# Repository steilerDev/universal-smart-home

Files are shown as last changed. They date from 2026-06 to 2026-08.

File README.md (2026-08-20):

# universal-smart-home

ESPHome firmware for the house: ~25 room sensor units plus a handful of special-purpose
nodes. Every device is an [Olimex ESP32-POE2](https://www.olimex.com/Products/IoT/ESP32/ESP32-POE2/open-source-hardware)
on PoE Ethernet — no WiFi, no cloud dependency. All devices integrate with Home
Assistant via the native ESPHome API. This repo is the single source of truth for
every device configuration.

---

## Hardware — Room Sensor

> [Schematic](https://app.cirkitdesigner.com/project/281a6c22-06b7-4593-8d16-d8be4f0f2b7c)

| Component | Part |
|---|---|
| MCU | [Olimex ESP32-POE2](https://www.olimex.com/Products/IoT/ESP32/ESP32-POE2/open-source-hardware) (ESP32-WROVER-E, PoE Ethernet) |
| Climate | [ENS160](https://esphome.io/components/sensor/ens160/) + [AHT21](https://esphome.io/components/sensor/aht10/) — eCO2, TVOC, AQI, temp, humidity |
| Illuminance | [BH1750](https://esphome.io/components/sensor/bh1750/) |
| Presence | [DFRobot C4002](https://www.dfrobot.com/product-3081.html) mmWave radar (custom component) |
| Dimmer | [KRIDA I2C AC dimmer](https://www.tindie.com/products/bugrovs2012/i2c-mosfet-trailing-edge-ac-dimmer-light) trailing-edge MOSFET (custom component) |
| GPIO Expander | [PCF8574](https://esphome.io/components/pcf8574/) — 2 buttons, 2 power circuits, 2 roller blinds |
| Status LED | WS2811/WS2812 via [esp32_rmt_led_strip](https://esphome.io/components/light/esp32_rmt_led_strip/) |
| Audio | [ES8311](https://esphome.io/components/audio_dac/es8311/) + NS4150B (notifications / TTS) |
| Power | [PZEM-004T](https://esphome.io/components/sensor/pzemac/) AC energy monitor |

PCB design files live in `hardware/pcb/`, the enclosure in `hardware/case/room-sensor/`.

---

## Hardware — Utility Sensor

The basement metering node. Same Olimex board, **no custom PCB** — the field wiring
lands on screw terminals — but it does have its own case (`hardware/case/utility-sensor/`).

| Component | Part |
|---|---|
| MCU | Olimex ESP32-POE2, running the `esp-idf` framework (8 × PCNT pulse counters) |
| Water flow | 8 × YF-B series hall-effect meters, one per supply line |
| Well level | QDY30A submersible level transmitter (Modbus RTU over RS485) |
| Grid power | Eastron SDM three-phase meter (Modbus RTU) — wired for, **not yet populated** |

Schematic (WIP): https://app.cirkitdesigner.com/project/46fdfdfb-f6f8-4aec-ac91-cfc2bc7dc07d

### Metered lines

| Line | GPIO | Line | GPIO |
|---|---|---|---|
| EG Kalt | GPIO04 | EG Warm | GPIO36 |
| OG Kalt | GPIO33 | OG Warm | GPIO13 |
| EG Heizung | GPIO15 | OG Heizung | GPIO02 |
| Anbau Heizung | GPIO14 | Brunnen | GPIO05 |

### Calibration

Both are build-time values in `devices/utility-sensor.yaml` — change and re-flash.

- **Water meters** — `flow_pulses_per_liter` per line. Meter datasheets quote
  `F = K * Q` (F in Hz, Q in L/min), so pulses/L is `K * 60`; the YF-B's K = 6.6 gives
  396. Each line carries its own value, so lines with a different meter model just get
  a different number.

  After changing a line's calibration, **re-flash and then press its
  `Water Volume Reset - <line>` button in HA**. The running total is stored in flash
  keyed by entity, so it survives the OTA and would otherwise keep the volume that
  was accumulated with the old pulses/L.
- **Well level** — the probe measures the water column above *itself*. The published
  value is the column above the **pump intake**:
  `raw + (well_pump_depth_cm - well_sensor_depth_cm)`. The offset is +100 cm in this
  install (probe at 15 m, intake at 16 m); it would be negative if the probe hung
  below the intake. Negative readings mean the water is below the intake and are not
  clamped away.

  ⚠️ Because the probe sits **above** the intake it cannot see a surface below itself,
  so the last 100 cm above the intake all read 100 cm — a floor, not a level. The
  `Well Probe Uncovered` binary sensor (`device_class: problem`) is ON exactly then, so
  automations can treat that reading as "≤100 cm, unknown" rather than trusting it.
  Hanging the probe below the intake would remove the blind spot.

### Home Assistant water dashboard

The `Water Volume - <line>` sensors carry `device_class: water` +
`state_class: total_increasing`, which is what HA's water dashboard filters on. A unit
of `L` alone is not enough — the entity simply never appears in the picker without
both of those.

---

## Repository Layout

```
devices/          — One YAML per physical device (substitutions + package includes)
packages/
  base/           — Board, Ethernet, OTA, HA API (room-sensor / utility-sensor variants)
  sensors/        — climate, illuminance, motion, power-pzem004t, water-flow,
                    well-level, energy-sdm
  actuators/      — status-led, dimmer, audio
  io/             — gpio-extender (PCF8574 — buttons, power circuits, blinds)
  displays/       — trmnl (e-ink dashboard)
components/       — Local custom ESPHome components (dfrobot_c4002, krida_dimmer, trmnl)
hardware/
  pcb/            — KiCad projects, symbol/footprint libs, LCSC BOM
  case/           — Fusion 360 enclosures, one directory per device
deploy/           — Device Builder deployment notes
scripts/          — validate-all, builder-deploy, deploy, new-device, check-device
sounds/           — WAV assets for the audio package
secrets.template.yaml
```

---

## Deployed Devices

| Device | IP | Packages |
|---|----|---|
| `room-sensor-poe2` (prototype) | 10.10.14.20 | base, power, climate, motion, status\_led |
| `eink-dashboard` | 10.10.14.25 | base, trmnl |
| `utility-sensor` | 10.10.14.10 | base, well\_level, 8 × water\_flow |

---

## Quick Start

Firmware is compiled and OTA-flashed by the self-hosted **ESPHome Device Builder**,
not by compiling locally — see [`deploy/README.md`](deploy/README.md).

```bash
cp secrets.template.yaml secrets.yaml  # fill in OTA password + HA encryption key

esphome config devices/<name>.yaml     # 1. validate (cheap, no compile)
./scripts/builder-deploy.py <name>     # 2. compile + OTA on the builder
./scripts/check-device.py <name>       # 3. post-deploy health check
```

Add a new device:

```bash
./scripts/new-device.sh <room-name>
```

Local compilation (`pip3 install esphome --break-system-packages`, then
`esphome run devices/<name>.yaml`) still works as a fallback; see `CLAUDE.md` for the
PlatformIO workarounds it needs.

---

## Packages

Each device YAML picks only the packages it needs. Every device requires exactly one
`base` package; the rest are optional.

| Package | Provides |
|---|---|
| `base/room-sensor` | Board (arduino), Ethernet PoE, OTA, HA API, I2C bus |
| `base/utility-sensor` | Board (esp-idf), Ethernet PoE, OTA, HA API — no I2C |
| `sensors/climate` | [ENS160](https://esphome.io/components/sensor/ens160/) + [AHT20](https://esphome.io/components/sensor/aht10/) — air quality, temp, humidity |
| `sensors/illuminance` | [BH1750](https://esphome.io/components/sensor/bh1750/) light level |
| `sensors/motion` | [DFRobot C4002](https://www.dfrobot.com/product-3081.html) presence + target tracking |
| `sensors/power-pzem004t` | [PZEM-004T](https://esphome.io/components/sensor/pzemac/) AC voltage/current/power/energy |
| `sensors/water-flow` | Pulse water meter for one supply line — include once per line with `vars` |
| `sensors/well-level` | QDY30A submersible level transmitter over Modbus |
| `sensors/energy-sdm` | Eastron SDM three-phase grid meter over Modbus |
| `actuators/dimmer` | [KRIDA I2C AC dimmer](https://www.tindie.com/products/bugrovs2012/i2c-mosfet-trailing-edge-ac-dimmer-light) (light entity) |
| `actuators/status-led` | WS2811/WS2812 status LED via [esp32_rmt_led_strip](https://esphome.io/components/light/esp32_rmt_led_strip/) |
| `actuators/audio` | [ES8311](https://esphome.io/components/audio_dac/es8311/) I2S media player |
| `io/gpio-extender` | [PCF8574](https://esphome.io/components/pcf8574/) — buttons, switches, blind covers |
| `displays/trmnl` | TRMNL BYOS e-ink dashboard client (custom component) |

`sensors/water-flow` is the one package meant to be included several times per device.
Use the mapping form of `!include` to pass it per-instance variables:

```yaml
packages:
  flow_eg_kalt: !include
    file: ../packages/sensors/water-flow.yaml
    vars:
      flow_key: eg_kalt
      flow_name: "EG Kalt"
      flow_pin: "GPIO04"
      flow_pulses_per_liter: "396"
```

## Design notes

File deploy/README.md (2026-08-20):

# Deploying firmware via the ESPHome Device Builder

Firmware is compiled and OTA-flashed by the self-hosted **ESPHome Device Builder**
container, not by compiling in the agent's environment.

```
host checkout ──bind-mount──► esphome (builder)   (runs the builder on devices/)
              └─bind-mount──► coder / agent      (edits devices/*.yaml)
                                 │  same files — edits are visible instantly ↑
  agent ── ws://esphome:6052/ws (no auth) ──────┘  compile + OTA
  browsers ── https://esphome.<domain> ── Authentik SSO ──► esphome (builder)
```

- **Shared mount, no git-sync** — the agent and the builder see the *same* files on
  disk, so a YAML edit is visible to the builder immediately. No commit or push is
  required to flash.
- **Git stays the source of truth** — `commit + push` is a durability step *after* a
  successful deploy, not part of the deploy path.
- **No auth for the agent** — it reaches the builder directly on the internal Docker
  network. The builder's native auth is unset (`requires_auth: false`); Authentik only
  gates the browser UI.

## Builder endpoint

| | |
|---|---|
| WebSocket API (agent) | `ws://esphome:6052/ws` |
| Browser UI | `https://esphome.<domain>` (Authentik SSO) |

Set `ESPHOME_BUILDER_URL=ws://esphome:6052/ws` in the agent's environment, or pass
`--server` to `scripts/builder-deploy.py`.

## Deploy loop

```bash
esphome config devices/room-sensor-poe2.yaml   # 1. validate locally (cheap, no compile)
./scripts/builder-deploy.py room-sensor-poe2   # 2. compile + OTA on the builder, streamed
./scripts/check-device.py room-sensor-poe2     # 3. health check
git add -A && git commit -m "…" && git push origin main   # 4. persist (durability)
```

The `deploy-device` skill codifies this loop.

`scripts/builder-deploy.py` speaks the builder's single `/ws` endpoint, streams job
output, and exits non-zero if any job fails. `--all` deploys every device;
`--compile-only` skips the OTA upload.

**A deploy is two jobs, not one.** On this builder (1.0.12 / ESPHome 2026.6.2)
`firmware/install` only *compiles* — its job ends at "Successfully compiled program"
and never contacts the device. The OTA is a separate `firmware/upload` job
(`job_type: upload`). The script runs `firmware/install` → `firmware/upload`, each
followed via `firmware/follow_job`. Calling install alone reports a green deploy
while the device keeps running its old firmware.

## Troubleshooting

| Symptom | Cause |
|---|---|
| `firmware/upload`: `Connecting to <ip> port 3232 failed: [Errno 113] No route to host` | **Nothing answers at that IP.** Port 3232 is the ESPHome OTA port; ARP finding no host produces this error, which reads like a routing fault but usually means `device_ip` is wrong (or the device is powered down). Verify the address before touching any network config. |
| `firmware/install` says SUCCESS but the device behaves as before | Expected — install only compiles. The OTA is the separate `firmware/upload` job; see above. |

## Why the builder's config dir points at `devices/`

The builder's config scanner (`list_yaml_files`) is **top-level only** and skips
`secrets.yaml` and dotfiles. Our device YAMLs live in `devices/` and
`!include ../packages/...`, so the container mounts the **whole repo** but runs the
dashboard against the `devices/` subdirectory. Includes,
`external_components: ../components`, and the `devices/secrets.yaml → ../secrets.yaml`
symlink all resolve because the parent tree is present on disk.

`secrets.yaml` is gitignored and lives at the checkout **root**; the committed
`devices/secrets.yaml` symlink points at it, so the builder finds secrets when
compiling `devices/*.yaml`.

## Notes

- **Source of truth is the YAML in git.** Treat the builder UI as deploy/observe only;
  set friendly names via device-YAML `substitutions`, so the gitignored builder state
  (`.device-builder*.json`) stays disposable.
- The builder image's default `CMD` is `dashboard /config`; its entrypoint rewrites the
  `dashboard` subcommand to the Device Builder backend (`esphome-device-builder`). Any
  other first arg is passed to the plain `esphome` CLI, so the builder `command` **must**
  begin with `dashboard`. Verified on 2026.6.2 and 2026.6.5. Pin a tag instead of
  `:latest` for reproducibility.

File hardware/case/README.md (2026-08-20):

# Cases

One directory per enclosure. Each holds the Fusion 360 source plus its exports.

| Case | For | Custom PCB? |
|---|-----|---|
| [`room-sensor/`](room-sensor/) | Room sensor units (~25×) | Yes — `hardware/pcb/RoomSensor-{Main,Back}Plate` |
| [`utility-sensor/`](utility-sensor/) | Utility sensor (basement metering) | No — Olimex board + screw terminals only |

## File conventions

- `*.f3d` — Fusion 360 native source (the editable master)
- `*.step` — STEP export, opens without Fusion 360
- `*.stl` — print-ready mesh
- `renders/` — PNG renders exported from Fusion 360

CAD files are marked `binary` in `.gitattributes` so git never tries to diff or
merge them. That also means **they do not merge** — coordinate before editing one.

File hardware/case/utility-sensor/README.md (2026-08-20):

# Utility Sensor Case

Custom enclosure for the basement metering unit, designed in Fusion 360.

Unlike the room sensors this device has **no custom PCB** — it is a stock
[Olimex ESP32-POE2](https://www.olimex.com/Products/IoT/ESP32/ESP32-POE2/open-source-hardware)
with the water-meter and RS485 wiring landed straight on screw terminals. The
case is therefore the only custom-fabricated part, which is why it is tracked
here on its own.

## What it has to hold

| Item | Notes |
|---|---|
| Olimex ESP32-POE2 | Standoffs; RJ45 must reach the wall |
| 8 × water meter leads | Pulse + 3.3V + GND per line — see `devices/utility-sensor.yaml` for the GPIO map |
| RS485 leg → well probe | QDY30A submersible level transmitter |
| RS485 leg → grid meter | Eastron SDM — wired for, not yet populated |

## Design Files

- `*.f3d` — Fusion 360 native source (stored as binary in git)
- `*.step` — STEP export (open without Fusion 360)
- `*.stl` — print-ready STL export
- `renders/` — PNG renders exported from Fusion 360

> ⚠️ **The CAD files are not in the repo yet.** The device was built before this
> repo existed. Export the current Fusion 360 design into this directory
> (`.f3d` + `.step` + `.stl`) so the case stops living only in someone's Fusion
> cloud project.

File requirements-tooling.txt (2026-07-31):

# Tooling deps for the scripts/ helpers (not firmware deps).
#   pip3 install -r requirements-tooling.txt
websockets>=13        # scripts/builder-deploy.py  (Device Builder /ws client)
aioesphomeapi         # scripts/check-device.py    (native-API health check)
PyYAML                # device/secret YAML parsing in scripts/

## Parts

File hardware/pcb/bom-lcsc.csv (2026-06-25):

MPN | LCSC# | Qty (1 board set) | Description | Refs
C50950 | C50950 | 2 | 1x5 female socket 8.5mm | MainPlate S1, S2
C27438 | C27438 | 1 | 1x8 female socket 8.5mm | MainPlate S3
PM254-1-10-Z-8.5 | C2897373 | 1 | 1x10 female socket 8.5mm | MainPlate A1
C64320 | C64320 | 1 | 2x13 dual female socket 8.5mm | MainPlate E1
KF128-2.54-4P | C474922 | 5 | 4-pin screw terminal 2.54mm | MainPlate C1, C2 + BackPlate EX1, EX2, EX3
KF128-2.54-7P | C474925 | 1 | 7-pin screw terminal 2.54mm | MainPlate C3
MTB10-10S | C358743 | 2 | IDC 2x5 box header 2.54mm PCB side | MainPlate J1, BackPlate C1
HX PM2.54-1x4P ZC H11 | C41427519 | 5 | 4-pin tall female socket 11mm | BackPlate R1, R2, R3, L1, E1
PCF8574P | C398073 | 1 | DIP-16 I2C GPIO expander | BackPlate U1

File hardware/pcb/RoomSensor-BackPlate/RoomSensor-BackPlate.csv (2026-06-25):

Qty | MPN
1 | 2.54-2*5P
5 | HX PM2.54-1x4P ZC H11
3 | KF128-2.54-4P
1 | PCF8574P
1 | PM254-1-10-Z-8.5
2 | KF128-2.54-4P
1 | KF128-2.54-7P
1 | 2.54-2*13PFemale
1 | 2.54-2*5P
2 | 2.54-1*5PFemale
1 | 2.54-1*8P

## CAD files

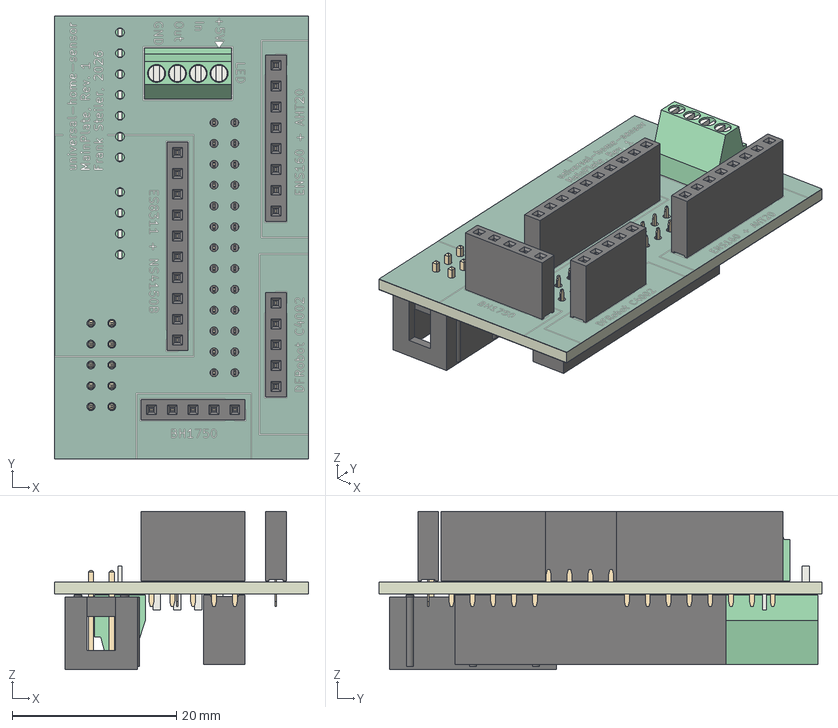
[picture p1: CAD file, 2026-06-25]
hardware/pcb/RoomSensor-MainPlate/MainPlate.step
31.0 x 54.0 x 19.3 mm
PinSocket_1x08_P2.54mm_Vertical
PinSocket_1x05_P2.54mm_Vertical x 2
PinSocket_1x10_P2.54mm_Vertical
TerminalBlock_Phoenix_MPT-0,5-4-2.54_1x04_P2.54mm_Horizontal x 2
TerminalBlock_Phoenix_MPT-0,5-7-2.54_1x07_P2.54mm_Horizontal
PinSocket_2x13_P2.54mm_Vertical
IDC_Header_2x05_P254mm_Vertical
RoomSensor-MainPlate_silkscreen x 2
RoomSensor-MainPlate_soldermask x 2
RoomSensor-MainPlate_PCB

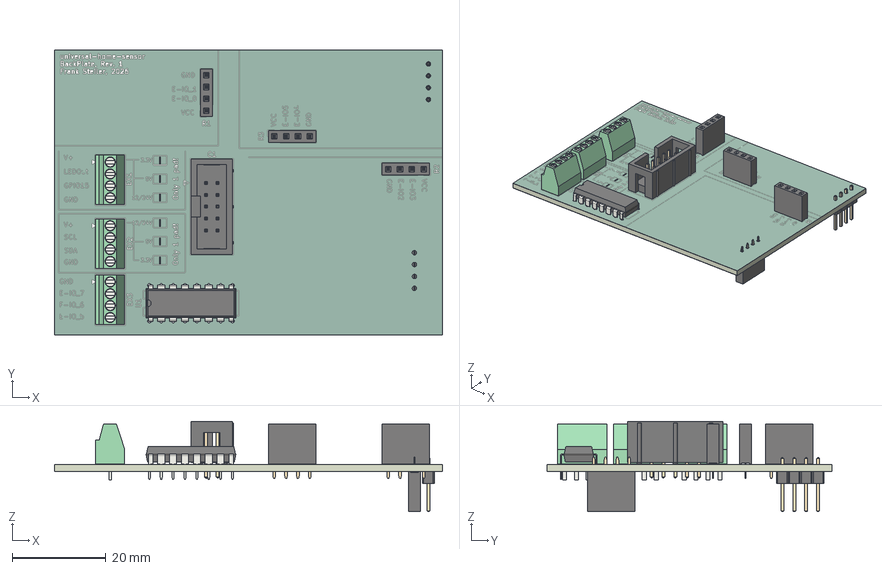
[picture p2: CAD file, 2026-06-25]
hardware/pcb/RoomSensor-BackPlate/BackPlate.step
83.0 x 61.0 x 19.3 mm
PinSocket_1x04_P2.54mm_Vertical x 4
DIP-16_W7.62mm
TerminalBlock_Phoenix_MPT-0,5-4-2.54_1x04_P2.54mm_Horizontal x 3
IDC_Header_2x05_P254mm_Vertical
PinHeader_1x04_P254mm_Vertical
RoomSensor-BackPlate-unsaved-export-98Ihw8_silkscreen x 2
RoomSensor-BackPlate-unsaved-export-98Ihw8_soldermask x 2
RoomSensor-BackPlate-unsaved-export-98Ihw8_PCB

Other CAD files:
hardware/pcb/RoomSensor-BackPlate/BackPlate.stl

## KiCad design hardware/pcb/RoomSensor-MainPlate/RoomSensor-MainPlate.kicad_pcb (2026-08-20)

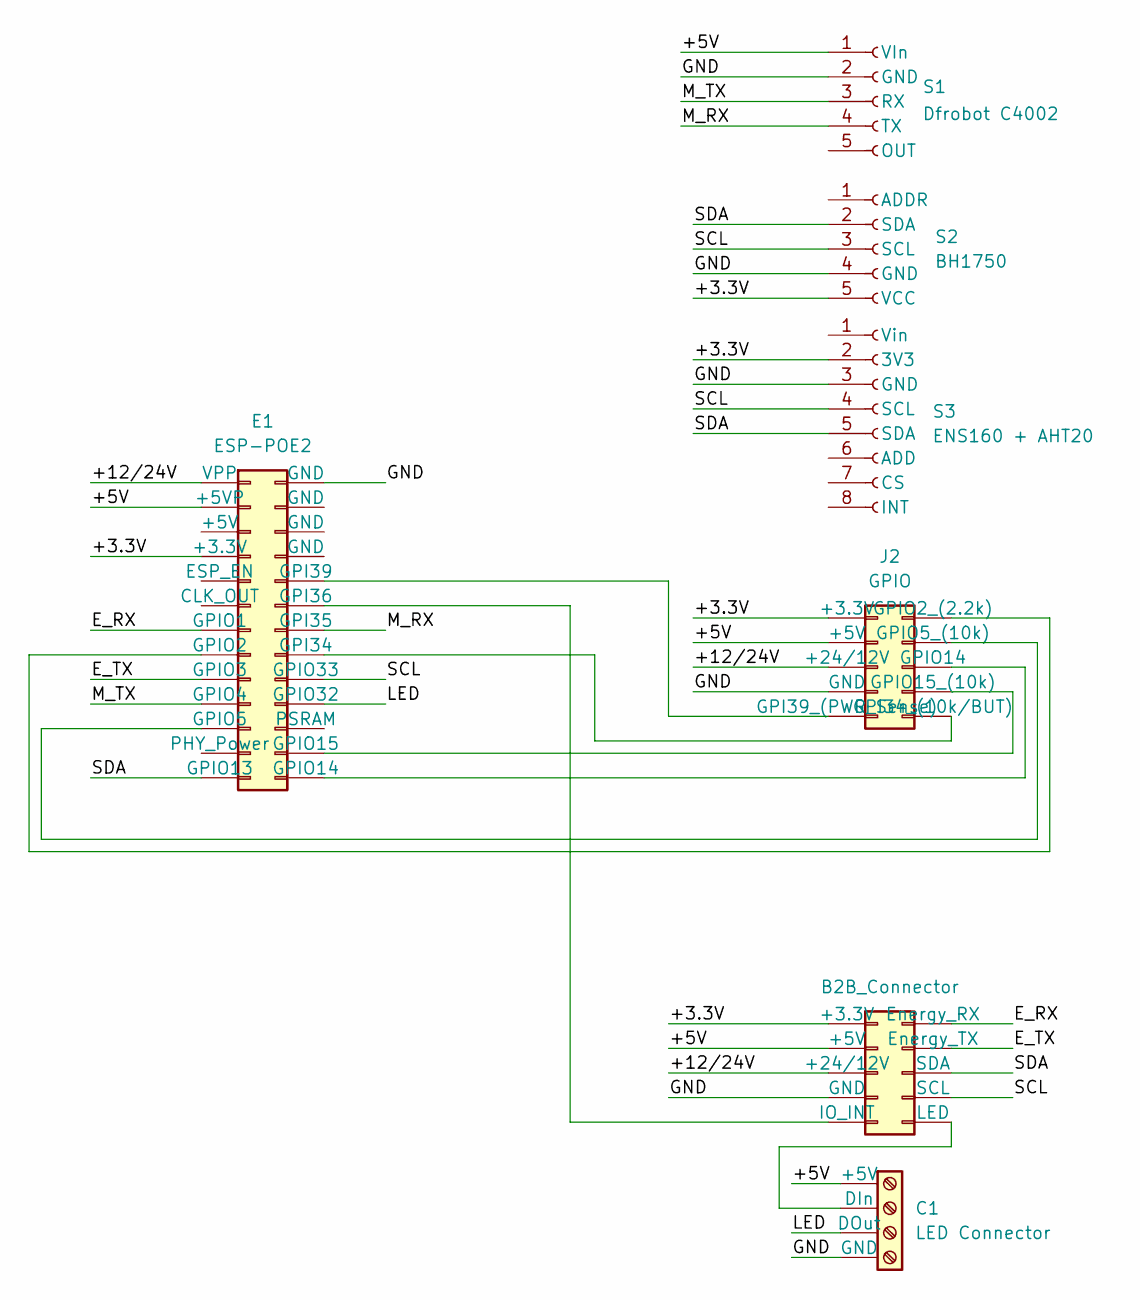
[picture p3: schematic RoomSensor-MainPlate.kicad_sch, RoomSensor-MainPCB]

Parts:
C1: LED Connector; TerminalBlock_Phoenix_MPT-0,5-4-2.54_1x04_P2.54mm_Horizontal; MPN KF128-2.54-4P
E1: ESP-POE2; PinSocket_2x13_P2.54mm_Vertical; MPN C64320
J1: B2B_Connector; B2B Connector; MPN MTB10-10S
J2: GPIO; IDC-Header_2x05_P2.54mm_Vertical; MPN MTB10-10S
S1: Dfrobot C4002; DFRobot C4002 Connector; MPN C50950
S2: BH1750; MPN C50950
S3: ENS160 + AHT20; ENS160 + AHT20 Connector; MPN C27438

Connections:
/+3.3V: E1.7 (+3.3V), J1.1 (+3.3V), J2.1 (+3.3V), S2.5 (VCC), S3.2 (3V3)
/+5V: C1.1 (+5V), E1.3 (+5VP), J1.3 (+5V), J2.3 (+5V), S1.1 (VIn)
/+12/24V: E1.1 (VPP), J1.5 (+24/12V), J2.5 (+24/12V)
/E_RX: E1.13 (GPIO1), J1.2 (Energy_RX)
/E_TX: E1.17 (GPIO3), J1.4 (Energy_TX)
/GND: C1.4 (GND), E1.2 (GND), J1.7 (GND), J2.7 (GND), S1.2 (GND), S2.4 (GND), S3.3 (GND)
/LED: C1.3 (DOut), E1.20 (GPIO32)
/M_RX: E1.14 (GPI35), S1.4 (TX)
/M_TX: E1.19 (GPIO4), S1.3 (RX)
/SCL: E1.18 (GPIO33), J1.8 (SCL), S2.3 (SCL), S3.4 (SCL)
/SDA: E1.25 (GPIO13), J1.6 (SDA), S2.2 (SDA), S3.5 (SDA)
unnamed: C1.2 (DIn), J1.10 (LED)
unnamed: E1.16 (GPI34), J2.10 (GPI34_(10k/BUT))
unnamed: E1.12 (GPI36), J1.9 (IO_INT)
unnamed: E1.10 (GPI39), J2.9 (GPI39_(PWR_Sense))
unnamed: E1.15 (GPIO2), J2.2 (GPIO2_(2.2k))
unnamed: E1.21 (GPIO5), J2.4 (GPIO5_(10k))
unnamed: E1.26 (GPIO14), J2.6 (GPIO14)
unnamed: E1.24 (GPIO15), J2.8 (GPIO15_(10k))

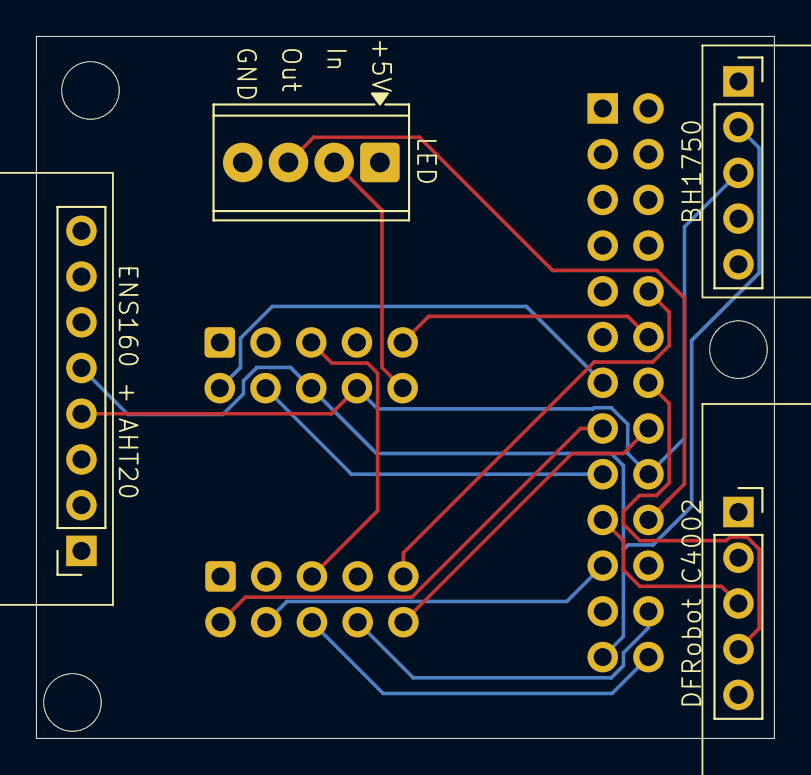
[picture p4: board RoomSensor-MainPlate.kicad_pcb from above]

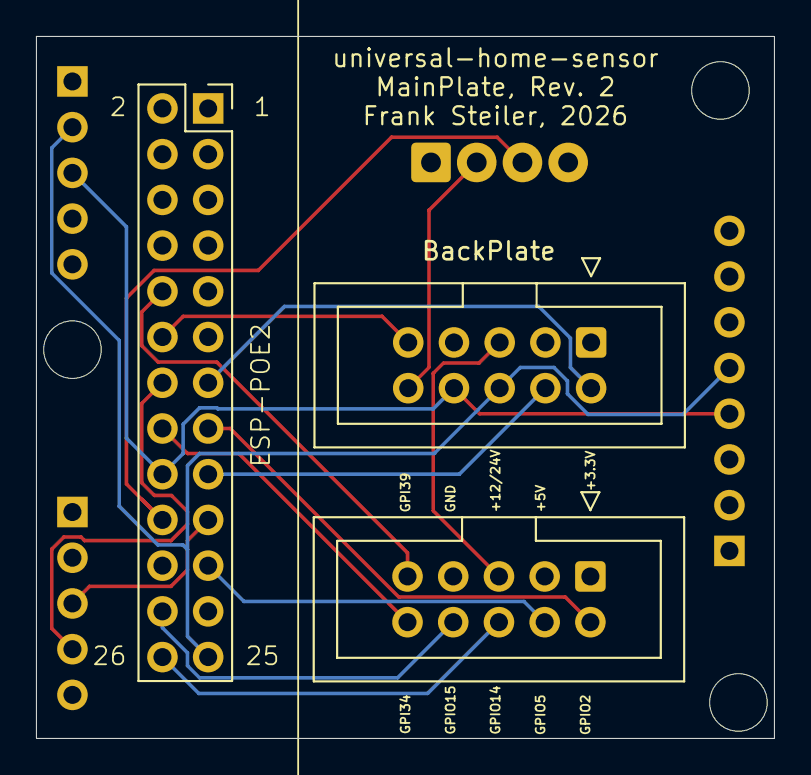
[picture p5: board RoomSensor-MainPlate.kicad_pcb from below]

Board: 4 copper layers, 41.0 x 39.0 mm, 7 parts (3 on the bottom side), 19 nets.

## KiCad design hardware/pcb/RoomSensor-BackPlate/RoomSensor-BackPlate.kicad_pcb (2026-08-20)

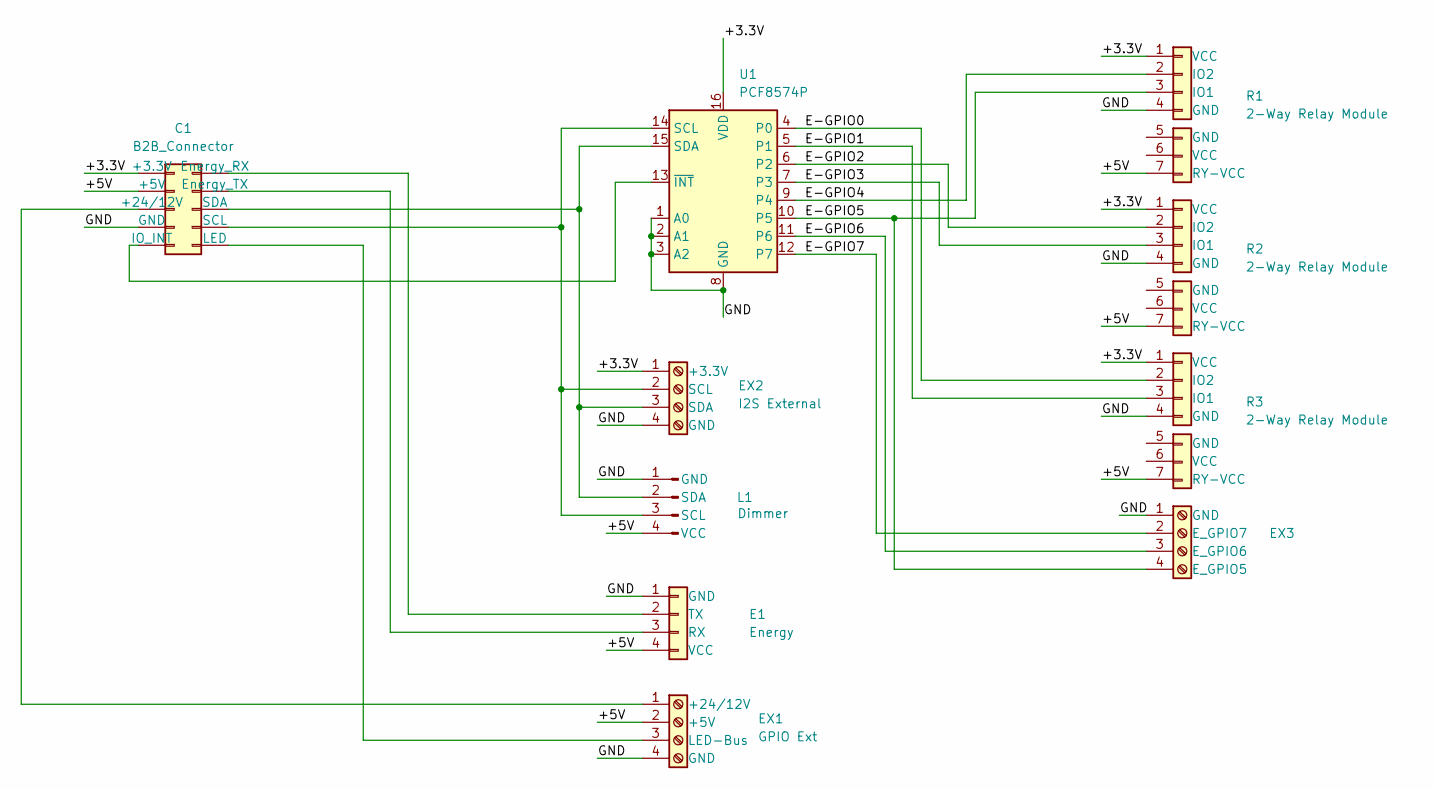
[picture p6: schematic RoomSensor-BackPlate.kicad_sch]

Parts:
C1: B2B_Connector; IDC-Header_2x05_P2.54mm_Vertical; MPN MTB10-10S
E1: Energy; PZEM-004T Connector; MPN HX PM2.54-1x4P ZC H11
EX1: GPIO Ext; TerminalBlock_Phoenix_MPT-0,5-4-2.54_1x04_P2.54mm_Horizontal; MPN KF128-2.54-4P
EX2: I2S External; TerminalBlock_Phoenix_MPT-0,5-4-2.54_1x04_P2.54mm_Horizontal; MPN KF128-2.54-4P
EX3: Buttons; TerminalBlock_Phoenix_MPT-0,5-4-2.54_1x04_P2.54mm_Horizontal; MPN KF128-2.54-4P
L1: Dimmer; Krida Dimmer I2C Connector; MPN HX PM2.54-1x4P ZC H11
R1, R2, R3: 2-Way Relay Module; 2-way Relay Connector; MPN HX PM2.54-1x4P ZC H11
U1: PCF8574P; DIP-16_W7.62mm; MPN PCF8574P

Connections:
/+3.3V: C1.1 (+3.3V), EX2.1 (+3.3V), R1.1 (VCC), R2.1 (VCC), R3.1 (VCC), U1.16 (VDD)
/+5V: C1.3 (+5V), E1.4 (VCC), EX1.2 (+5V), L1.4 (VCC), R1.7 (RY-VCC), R2.7 (RY-VCC), R3.7 (RY-VCC)
/E-GPIO0: R3.2 (IO2), U1.4 (P0)
/E-GPIO1: R3.3 (IO1), U1.5 (P1)
/E-GPIO2: R2.2 (IO2), U1.6 (P2)
/E-GPIO3: R2.3 (IO1), U1.7 (P3)
/E-GPIO4: R1.2 (IO2), U1.9 (P4)
/E-GPIO5: EX3.4 (E_GPIO5), R1.3 (IO1), U1.10 (P5)
/E-GPIO6: EX3.3 (E_GPIO6), U1.11 (P6)
/E-GPIO7: EX3.2 (E_GPIO7), U1.12 (P7)
/GND: C1.7 (GND), E1.1 (GND), EX1.4 (GND), EX2.4 (GND), EX3.1 (GND), L1.1 (GND), R1.4 (GND), R2.4 (GND), R3.4 (GND), U1.1 (A0), U1.2 (A1), U1.3 (A2), U1.8 (GND)
unnamed: C1.5 (+24/12V), EX1.1 (+24/12V)
unnamed: C1.2 (Energy_RX), E1.2 (TX)
unnamed: C1.4 (Energy_TX), E1.3 (RX)
unnamed: C1.9 (IO_INT), U1.13 (~INT)
unnamed: C1.10 (LED), EX1.3 (LED-Bus)
unnamed: C1.8 (SCL), EX2.2 (SCL), L1.3 (SCL), U1.14 (SCL)
unnamed: C1.6 (SDA), EX2.3 (SDA), L1.2 (SDA), U1.15 (SDA)

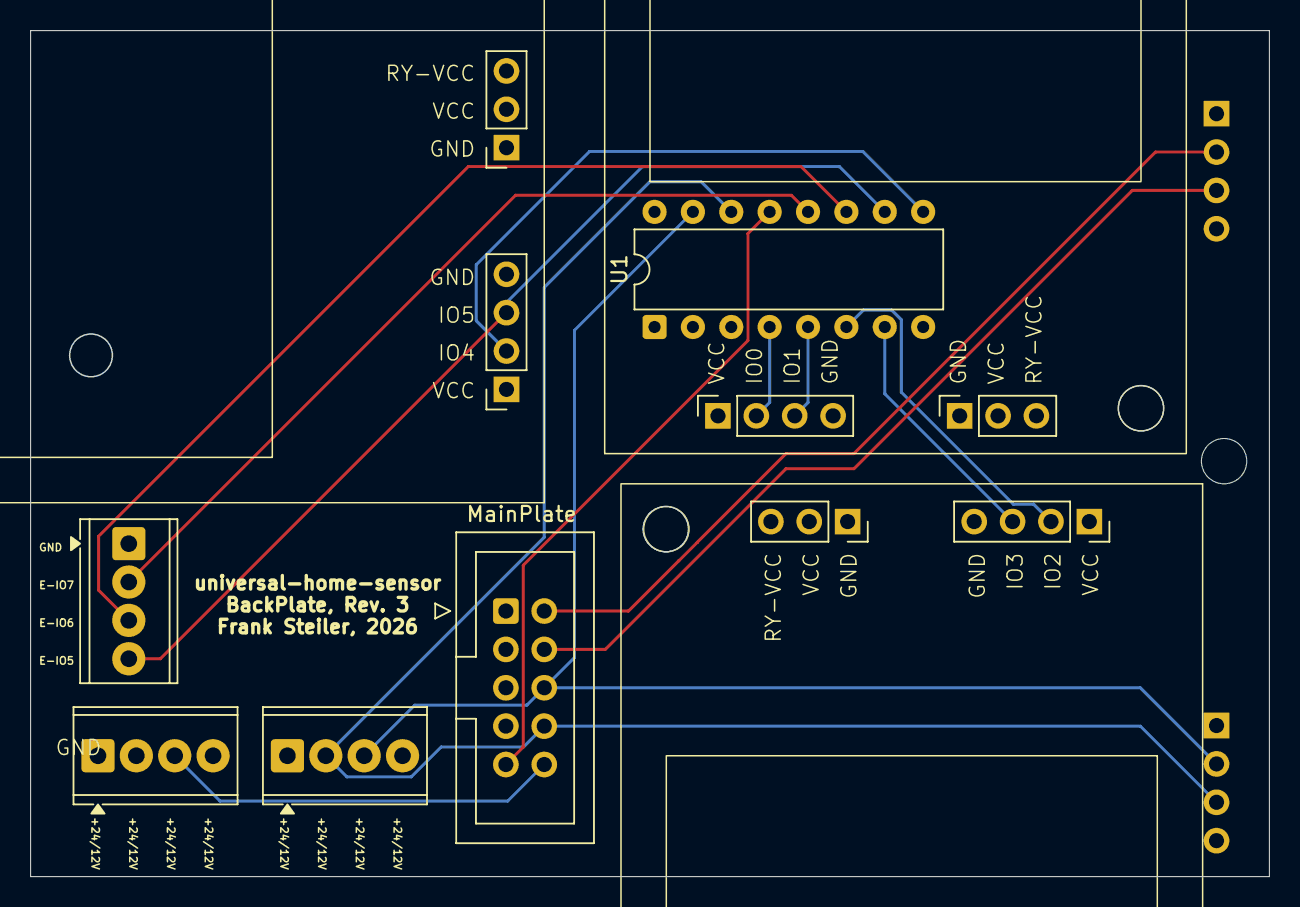
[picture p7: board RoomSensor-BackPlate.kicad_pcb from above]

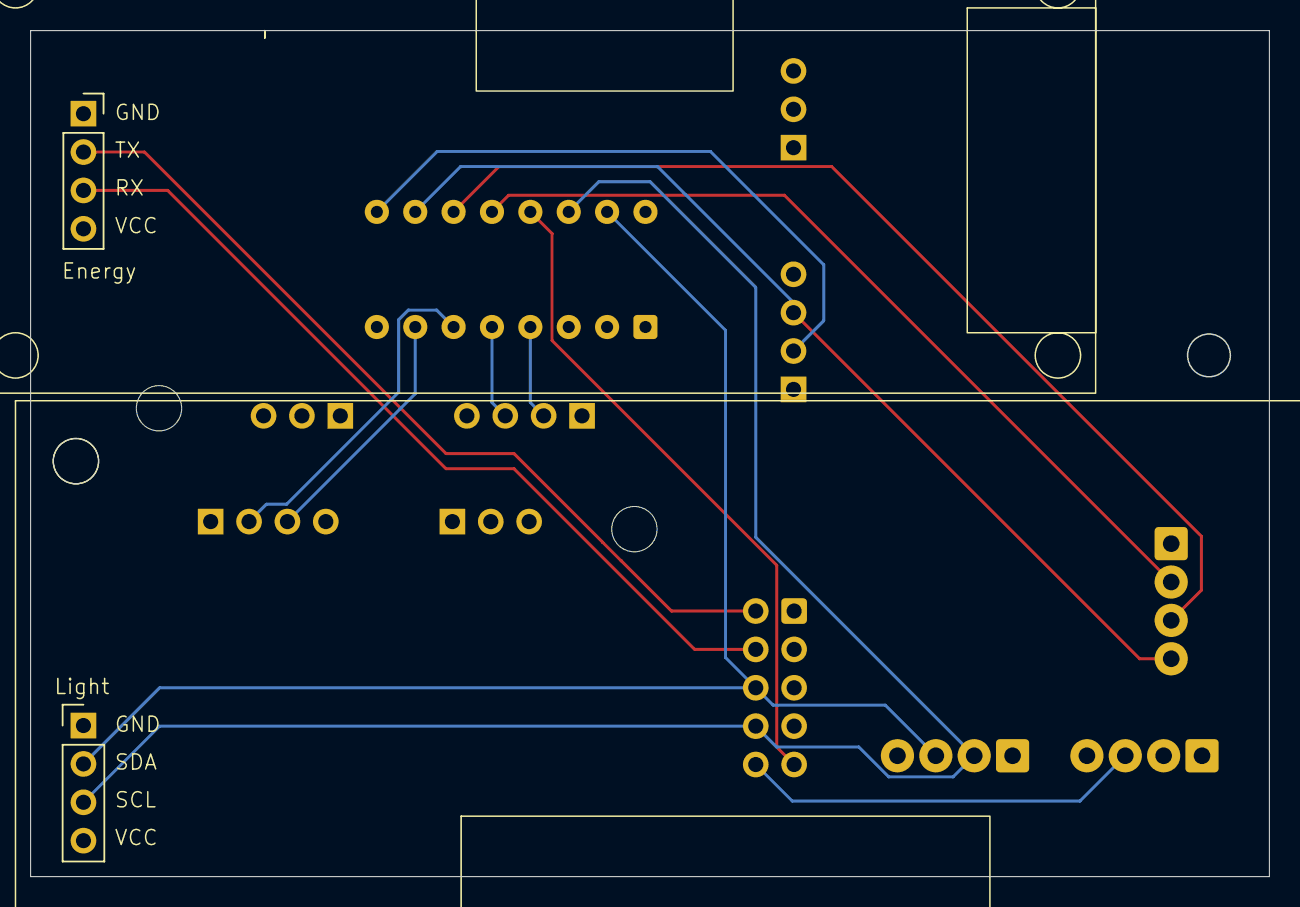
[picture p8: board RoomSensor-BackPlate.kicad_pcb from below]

Board: 4 copper layers, 82.0 x 56.0 mm, 10 parts (2 on the bottom side), 18 nets.

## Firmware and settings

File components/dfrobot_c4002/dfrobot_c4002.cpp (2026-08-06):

#include "dfrobot_c4002.h"
#include <string>
#include <cstdio>

namespace esphome {
namespace dfrobot_c4002 {

static const char *const TAG = "dfrobot_c4002: ";

void C4002Component::setup() {
  update_config_param();
  if (!this->is_failed()) {
    this->publish_text("C4002 initialized");
  }
}

void C4002Component::dump_config() {
  ESP_LOGCONFIG(TAG, "DFRobot C4002 mmWave Radar:");
  if (this->is_failed()) {
    if (this->last_uart_probe_bytes_ == 0) {
      ESP_LOGE(TAG, "  FAILED: no bytes received from sensor");
      ESP_LOGE(TAG, "  -> check power (VCC/GND) and that sensor TX -> ESP GPIO36");
    } else if (this->last_uart_probe_bytes_ > 0) {
      ESP_LOGE(TAG, "  FAILED: %d bytes received but frame invalid", this->last_uart_probe_bytes_);
      ESP_LOGE(TAG, "  -> possible baud rate mismatch or protocol error");
    } else {
      ESP_LOGE(TAG, "  FAILED: begin() not attempted (init error)");
    }
  } else {
    ESP_LOGCONFIG(TAG, "  Setup successful, detect range: %d cm", max_detect_range_cm_);
  }
}

void C4002Component::print_config() { ESP_LOGD(TAG, "run print config"); }

void C4002Component::loop() {
  static uint32_t last_time = 0;
  uint32_t now = millis();
  RetResult ret = {};

  ret = get_note_info_loop();
  if (ret.noteType == NOTE_INFO_RESULT) {
    ESP_LOGV(TAG, "NOTE_INFO_RESULT");
  } else if (ret.noteType == NOTE_INFO_CALIBRATION) {
    char msg[80];
    if (ret.calibCountdown > 0) {
      snprintf(msg, sizeof(msg), "Calibrating: %d s remaining...", ret.calibCountdown);
      this->publish_text(msg);
      ESP_LOGD(TAG, "Calibration countdown: %2d s", ret.calibCountdown);
    } else {
      // Calibration complete: read per-gate thresholds and apply sensitivity floor
      uint8_t cal_move[15] = {}, cal_exist[15] = {};
      get_distance_presence_threshold(MOVE_DIST_DOOR, cal_move);
      get_distance_presence_threshold(EXIST_DIST_DOOR, cal_exist);

      uint8_t sensitivity_floor = 0;
#ifdef USE_NUMBER
      if (sensitivity_threshold_number_ != nullptr && sensitivity_threshold_number_->has_state()) {
        sensitivity_floor = (uint8_t) sensitivity_threshold_number_->state;
      }
#endif

      uint8_t eff_move[15], eff_exist[15];
      uint8_t cal_min = 99, cal_max_val = 0;
      for (int i = 0; i < 15; i++) {
        if (cal_move[i] < cal_min) cal_min = cal_move[i];
        if (cal_move[i] > cal_max_val) cal_max_val = cal_move[i];
        if (cal_exist[i] < cal_min) cal_min = cal_exist[i];
        if (cal_exist[i] > cal_max_val) cal_max_val = cal_exist[i];
        eff_move[i] = (cal_move[i] > sensitivity_floor) ? cal_move[i] : sensitivity_floor;
        eff_exist[i] = (cal_exist[i] > sensitivity_floor) ? cal_exist[i] : sensitivity_floor;
      }
      set_distance_door_threshold(MOVE_DIST_DOOR, eff_move);
      set_distance_door_threshold(EXIST_DIST_DOOR, eff_exist);

      snprintf(msg, sizeof(msg), "Cal done. Range: %d-%d. Floor: %d.", cal_min, cal_max_val, sensitivity_floor);
      this->publish_text(msg);
      ESP_LOGD(TAG, "Calibration complete: %s", msg);
    }
  }

  if (now - last_time >= 1000) {
    last_time = now;
    get_data();
  }

  if (reset_flag_ == 1) {
    reset_flag_ = 0;
    restart();
    this->publish_text("Factory reset complete");
  }
}

void C4002Component::get_data() {
  TargetState target_state = get_target_state();
  for (auto &listener : this->listeners_) {
    if (listener != nullptr) {
      listener->on_target_status((uint8_t) target_state);
      listener->on_detection_detail((uint8_t) target_state, detect_result_.existDistIndex,
                                     detect_result_.existTargetDist, detect_result_.existTargetEnery,
                                     detect_result_.moveTargetDist, detect_result_.moveTargetEnery,
                                     detect_result_.moveTargetSpeed);
    }
  }
}

void C4002Component::update_config_param() {
  ESP_LOGD(TAG, "update config param");

  bool init_ok = false;
  for (int attempt = 1; attempt <= 3; attempt++) {
    this->uart_clear_buffer();
    if (begin()) {
      init_ok = true;
      break;
    }
    uint8_t probe[8] = {};
    size_t got = this->uart_read_raw(probe, sizeof(probe), 50);
    this->last_uart_probe_bytes_ = (int) got;
    ESP_LOGW(TAG, "C4002 begin failed (attempt %d/3) — %d bytes on UART (0=no power/wiring, >0=baud/protocol mismatch)",
             attempt, (int) got);
    delay(300);
  }
  if (!init_ok) {
    ESP_LOGE(TAG, "C4002 sensor not responding after 3 attempts — marking failed");
    this->mark_failed();
    return;
  }
  ESP_LOGI(TAG, "C4002 begin success");

  if (set_out_mode(OUT_MODE2)) {
    ESP_LOGD(TAG, "Output mode: presence-only (Mode_2)");
  }

  if (set_detect_range(0, (uint16_t) max_detect_range_cm_)) {
    ESP_LOGD(TAG, "Detect range: 0 - %d cm", max_detect_range_cm_);
  }

  set_run_led(LED_OFF);
  set_out_led(LED_OFF);

  float current_delay_time = (float) get_target_disappear_delay();
#ifdef USE_NUMBER
  if (target_disappeard_delay_time_number_ != nullptr) {
    target_disappeard_delay_time_number_->publish_state(current_delay_time);
  }
  if (sensitivity_threshold_number_ != nullptr) {
    uint8_t current_sensitivity = get_current_sensitivity_threshold();
    sensitivity_threshold_number_->publish_state(current_sensitivity);
    ESP_LOGD(TAG, "Sensitivity floor: %d", current_sensitivity);
  }
#endif

  if (set_report_period(10)) {
    ESP_LOGD(TAG, "set report period success");
  }
}

bool C4002Component::set_out_mode(OutMode out_mode) {
  uint8_t send_date[10];
  uint16_t data_len = 0;
  uint16_t temp = 5;
  send_date[data_len++] = CMD_CONFIG_OUT_MODE;
  send_date[data_len++] = READ_AND_WRITE_REQ;
  send_date[data_len++] = temp >> 0 & 0xFF;
  send_date[data_len++] = temp >> 8 & 0xFF;
  send_date[data_len++] = (uint8_t) out_mode;
  send_pack(send_date, data_len, FRAME_TYPE_WRITE_REQUSET);

  RecvPack rec_pack = recv_pack();
  if (SUCCEED == rec_pack.resPonCode) {
    out_mode_ = out_mode;
    return true;
  }
  return false;
}

bool C4002Component::factory_reset() {
  uint8_t send_date[10];
  uint16_t data_len = 5;

  // Vendor order: CMD_FACTORY_RESET_USER (0x02) first, then CMD_FACTORY_RESET (0x80)
  send_date[0] = CMD_FACTORY_RESET_USER;
  send_date[1] = READ_AND_WRITE_REQ;
  send_date[2] = data_len >> 0 & 0xFF;
  send_date[3] = data_len >> 8 & 0xFF;
  send_date[4] = 0x00;
  send_pack(send_date, data_len, FRAME_TYPE_WRITE_REQUSET);
  RecvPack rec_pack = recv_pack();
  if (SUCCEED != rec_pack.resPonCode) {
    return false;
  }
  delay(10);

  send_date[0] = CMD_FACTORY_RESET;
  send_pack(send_date, data_len, FRAME_TYPE_WRITE_REQUSET);
  rec_pack = recv_pack();
  if (SUCCEED != rec_pack.resPonCode) {
    return false;
  }
  reset_flag_ = 1;
  return true;
}
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

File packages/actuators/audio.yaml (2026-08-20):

# Package: ES8311 + NS4150B — I2S Audio (notification sounds / TTS)
#
# ⚠️ Rev 1 boards only. The MainPlate Rev 2/3 dropped the ES8311/NS4150B section
# entirely, and two of the Rev 1 audio pins are now spoken for: GPIO13 is I2C SDA
# and GPIO1 is the PZEM UART RX. There are therefore no Rev 2/3 defaults here —
# every pin below stays a required substitution so that including this package on
# a Rev 2/3 device fails loudly instead of quietly fighting the I2C bus.
# Bus: I2C for DAC control (bus_i2c defined in base/room-sensor.yaml), I2S for audio data
# ES8311 address: 0x18
# Required substitutions:
#   audio_bclk_pin    — I2S bit clock       (e.g. "GPIO5")
#   audio_lrclk_pin   — I2S LR clock        (e.g. "GPIO13")
#   audio_dout_pin    — I2S data out to DAC  (e.g. "GPIO14")
#   audio_din_pin     — I2S data in from mic (e.g. "GPIO15")
#   audio_mclk_pin    — I2S MCLK output     (must be GPIO0/1/3 on ESP32 — hardware CLK_OUT pins only)
#   device_friendly_name
# Note: MCLK on GPIO1 requires UART0 logger disabled; add logger: baud_rate: 0 in the device file.

i2s_audio:
  - id: bus_i2s
    i2s_lrclk_pin: ${audio_lrclk_pin}
    i2s_bclk_pin: ${audio_bclk_pin}
    i2s_mclk_pin: ${audio_mclk_pin}

audio_dac:
  - platform: es8311
    id: es8311_dac
    address: 0x18
    use_mclk: true
    use_microphone: false

speaker:
  - platform: i2s_audio
    id: i2s_speaker
    i2s_audio_id: bus_i2s
    dac_type: external
    audio_dac: es8311_dac
    i2s_dout_pin: ${audio_dout_pin}

media_player:
  - platform: speaker
    name: "${device_friendly_name} Speaker"
    id: media_player_speaker
    buffer_size: 32768
    announcement_pipeline:
      speaker: i2s_speaker
      format: FLAC

rtttl:
  id: rtttl_beeper
  speaker: i2s_speaker

microphone:
  - platform: i2s_audio
    id: mic_i2s
    i2s_audio_id: bus_i2s
    i2s_din_pin: ${audio_din_pin}
    adc_type: external
    pdm: false

# --- Voice assistant (future) ---
# voice_assistant:
#   microphone: mic_i2s
#   media_player: media_player_speaker

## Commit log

2026-06-10 Add full repo scaffold, packages, prototype device config, and tooling
    - packages/base, sensors, actuators, io — full package hierarchy for room sensors
    - devices/room-sensor-poe2.yaml — prototype device (10.10.14.20), OTA-verified
    - scripts/check-device.py — post-deploy health check via aioesphomeapi native API
    - scripts/deploy.sh, validate-all.sh, new-device.sh — operational tooling
    - CLAUDE.md — build environment docs, known issues, network policy requirements
    - devices/secrets.yaml symlink → ../secrets.yaml (gitignored actual file)
    - .gitignore, .gitattributes, secrets.template.yaml
    [audio.yaml]
2026-06-10 Add KRIDA single-channel I2C dimmer as local external component
    The tomavc/KRIDA_i2c_Dimmer_EspHome GitHub component targets the 4-channel
    module (2-byte protocol: channel + brightness 0-100). The single-channel
    Tindie product (0x10) reads a single byte 0-255, so a local component is
    needed to match the actual protocol.
    - components/krida_dimmer/ — local ESPHome external component using
    I2CDevice base class; writes one byte (0-255) per the Arduino firmware
    - packages/actuators/dimmer.yaml — updated to use local component
    - devices/room-sensor-poe2.yaml — dimmer package added
    - scripts/check-device.py — dimmer light entity name corrected to main_light
    - .gitignore — exclude __pyc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
2026-06-10 Document ESP32-POE2 GPIO constraints from official Olimex manual
    Adds a GPIO constraint table to CLAUDE.md covering hard-reserved pins
    (Ethernet, PSRAM), strapping pin boot requirements, our current PCB
    assignments with conflict notes (GPIO3/UART0, GPIO2/strapping), and
    available GPIOs for future components.
2026-06-10 Add DFRobot C4002 mmWave radar to prototype device
    - devices/room-sensor-poe2.yaml: motion package added
    - scripts/check-device.py: motion check spec updated to match actual C4002
    sensor entities (target_status, motion_distance, presence_distance)
    instead of the incorrect binary_sensor "presence"
    UART: tx=GPIO2, rx=GPIO36 (separate UART peripheral, no conflict with logger)
2026-06-10 fix: C4002 sensor crashing device on boot, switch to local component
    The external dfrobot_c4002 component had a while(!begin()) infinite
    blocking loop in setup(). When the sensor doesn't respond on UART,
    this looped forever with 300ms busy-waits (delayMicroseconds), fired
    the ESP32 watchdog, and triggered OTA rollback — leaving the device on
    the old firmware with no C4002 entities visible.
    Fix: copy component to components/dfrobot_c4002/ and change the init
    loop to 3 retries + mark_failed(), so a missing/unresponsive sensor
    marks the component failed without crashing the device.
    Also rename template text sensors ("Target Status Text",
    "Movement Direction Text") to avoid entity name colli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
2026-06-10 fix: add C4002 dump_config diagnostic and post-deploy log check doc
    dump_config() now reports whether begin() failed due to no bytes
    (power/wiring) or received bytes with wrong content (baud/protocol),
    visible immediately when connecting with esphome logs.
    Also stores last_uart_probe_bytes_ from the retry loop for the
    diagnostic. CLAUDE.md documents required post-deploy log check.
    [dfrobot_c4002.cpp]
2026-06-11 feat: C4002 LEDs off by default, hidden from HA UI
    Component init changed from LED_ON to LED_OFF so the sensor's run and
    out LEDs are dark on every boot. Switches kept in YAML but marked
    disabled_by_default so they're hidden from the HA dashboard (still
    accessible under the device's hidden entities if needed).
2026-06-11 feat: hide Radar Mode and Radar Log from HA by default
    Both entities are kept in the config but marked disabled_by_default
    so they don't appear in dashboards or automations. Still accessible
    under the device's hidden entities if needed.
2026-06-11 feat: runtime temp calibration, presence sensor, area persistence, cleaner HA entities
    Temperature:
    - Add runtime Temperature Calibration number (±10°C, persists via restore_value)
    applied as a filter on AHT20 so ENS160 compensation also uses the corrected value
    Motion / C4002:
    - Add Presence binary sensor (device_class: occupancy, delayed_off 5s) as the
    primary HA-facing entity; all raw radar diagnostics marked internal
    - Fix C4002 bug: area zone config was zeroed and pushed to radar on every reboot,
    wiping user-configured exclusion zones
    - Add ESP flash persistence for area values (load_area_prefs/save_area_prefs) so
    zones survive reboots without requiring a radar read-back comm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
    [dfrobot_c4002.cpp]
2026-06-12 feat: KRIDA dimmer — full-range brightness with min_power floor
    - Safe byte range capped at 250 (255/254 cause KRIDA firmware misbehavior)
    - min_power/max_power config options map HA 1–100% onto the LED's
    usable firing range; fade-to-off bypasses the floor so the LED
    drops out naturally
    - Read raw brightness via current_values.get_brightness() × get_state()
    instead of current_values_as_brightness(), which corrupts values when
    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
2026-06-12 chore: remove unused scaffold device configs
2026-06-12 feat: wire up PZEM-004T power monitor on GPIO1/GPIO39
    GPIO1 (UART0 TX) claimed for PZEM TX — serial logger disabled (baud_rate: 0)
    to free it; network/API logging unaffected. pzemac uses Modbus protocol so
    added modbus bridge between uart and sensor. Power factor hidden (internal).
    Verified on device: 50W halogen reads 0.234A / 56.5W / 241V / 50Hz.
2026-06-15 feat: wire up ES8311 audio — MCLK on GPIO1, PZEM TX to GPIO33, RTTTL button beep
    Swap PZEM UART TX from GPIO1 to GPIO33 to free GPIO1 for ES8311 MCLK
    (ESP32 hardware CLK_OUT is limited to GPIO0/1/3; GPIO0=Ethernet,
    GPIO3=I2C SDA). Configure ES8311 with use_mclk: true, wire mic (GPIO15)
    and speaker (GPIO14), add RTTTL beep on button_1 press. Add button IDs
    to gpio-extender package to allow extend. Update CLAUDE.md GPIO table.
    [audio.yaml]
2026-06-15 feat: expose motion sensor debug entities for presence tuning
    Remove internal: true from all C4002 diagnostic sensors (distances,
    speed, direction, target status, radar log) and operating mode select.
    Surfaced as entity_category: diagnostic in HA to aid diagnosing
    constant presence detection.
2026-06-23 Initial PCB design
    [RoomSensor-MainPlate.kicad_pcb, RoomSensor-MainPlate.kicad_sch]
2026-06-24 PCB Design
    [RoomSensor-BackPlate.kicad_pcb, RoomSensor-BackPlate.kicad_sch, RoomSensor-MainPlate.kicad_pcb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]
2026-06-25 PCB v1: restructure hardware/, add STEP models and BOMs
    Flatten hardware/room-sensor/pcb/ → hardware/pcb/ (repo is single-device).
    Add STEP models, STL, and per-board + combined LCSC BOMs for the first
    manufactured revision of RoomSensor-BackPlate and RoomSensor-MainPlate.
    Switch parts sourcing from Mouser DE to LCSC in CLAUDE.md.
    Add *-unsaved-export-*.kicad_prl to .gitignore.
    [BackPlate.step, BackPlate.stl, MainPlate.step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]
2026-06-25 hardware: move footprint/symbol libs into pcb/, update KiCad project settings
    Move room-sensor.pretty/ and room-sensor.kicad_sym into hardware/pcb/ so all
    PCB design files live under one directory. Also picks up KiCad project edits:
    BOM preset config and pin_to_pin ERC rule change to error on both plates.
    [RoomSensor-BackPlate.kicad_pcb, RoomSensor-BackPlate.kicad_sch, RoomSensor-MainPlate.kicad_pcb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]
2026-07-31 Colocate the Claude agent + ESPHome Device Builder in one Docker stack (#4)
    * feat: deploy via self-hosted ESPHome Device Builder over WebSocket API
    Offload firmware compile + OTA from the sandbox to a self-hosted ESPHome
    Device Builder on the primary Docker host, driven by the agent through git +
    the builder's /ws API. Git is the sync channel; the builder git-syncs main and
    does the heavy build.
    - scripts/builder-deploy.py: WebSocket client — mints an Authentik M2M JWT,
    connects to the single /ws endpoint, firmware/install -> follow_job, streams
    the job, exits non-zero on failure. Bearer with goauthentik.io/token Basic
    fallback; --all / --compile-only.
    - deploy/: docker-compose (b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
2026-07-31 fix(deploy): make the colocated stack build and run (image context + builder command) (#5)
    * fix(deploy): build the claude image without any repo file in the context
    The Dockerfile COPYed requirements-tooling.txt from the build context, which
    forced context: .. (the whole repo) and broke `docker compose build` whenever
    the service was invoked from a compose project whose `..` isn't the repo root
    (e.g. wired into an existing homelab stack): "requirements-tooling.txt: not found".
    The container needs the repo only at RUNTIME (the /repo bind mount), never at
    build time. Inline the pip deps (esphome websockets aioesphomeapi PyYAML) so the
    image builds with an empty context, and shrink the compo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
2026-07-31 io: remap PCF8574 pins — outputs 0-5, inputs 6-7 (#3)
    * io: remap PCF8574 pins — outputs 0-5, inputs 6-7
    Swap the expander layout so pins 0-5 are outputs and 6-7 are inputs,
    matching the updated PCB routing:
    0,1 -> Power Circuit 1,2 (was buttons)
    2,3 -> Blind 1 open/close (was power circuits)
    4,5 -> Blind 2 open/close (was blind 1)
    6,7 -> Button 1,2 (input) (was blind 2)
    Entity IDs, names, HA exposure, and cover wiring are unchanged — only
    the physical PCF8574 channel each maps to moves. Config validated with
    `esphome config devices/room-sensor-poe2.yaml`.
    * config: match latest prototype — I2C SDA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
2026-07-31 feat(room-sensor-poe2): add status LED (NeoPixel) on GPIO32 (#2)
    Include the status-led package on the prototype device. GPIO33 is already
    used by the PZEM UART TX here, so the NeoPixel is assigned to GPIO32 per the
    documented conflict-avoidance guidance in CLAUDE.md.
    Config validates and firmware compiles (Flash 46.8%).
2026-07-31 Sync CLAUDE.md GPIO docs with as-built pinout; fix RMII reserved pins (#6)
    * firmware: swap I2C pins to SDA=GPIO04 / SCL=GPIO03
    Matches the as-built PCB wiring. Also corrects the status-led package
    comment to GPIO32 (GPIO33 is taken by the PZEM-004T UART TX).
    * hardware: back plate mounting holes + EX2 routing, plot settings cleanup
    BackPlate: add four M3 mounting holes, re-place EX2 (I2S External) and
    route the remaining nets (+26 track segments, 7 new schematic wires).
    MainPlate: switch plot output to a repo-relative directory instead of a
    local Desktop path, add board outline/keepout drawings.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
    [RoomSensor-BackPlate.kicad_pcb, RoomSensor-BackPlate.kicad_sch, RoomSensor-MainPlate.kicad_pcb]
2026-07-31 feat: add e-ink TRMNL dashboard (device, displays package, trmnl component) (#1)
    ESP32-POE2 acting as a native TRMNL BYOS e-ink device against a
    self-hosted LaraPaper server.
    - devices/eink-dashboard.yaml — base + trmnl, SPI on GPIO13/14/15/32/33/35,
    I2C SDA=GPIO04/SCL=GPIO03 (matches the board's swapped I2C wiring)
    - packages/displays/trmnl.yaml — online_image + waveshare_epaper + trmnl
    - components/trmnl/ — custom external_component (BYOS device protocol)
2026-07-31 Edit room-sensor-poe2.yaml
2026-07-31 Quiet radar debug spam and fix device-check assertions
    dfrobot_c4002: demote two per-frame banner logs ("get note result" and
    "run print NOTE_INFO_RESULT") from DEBUG to VERBOSE. Each fired ~1/s per
    radar notification frame with no payload detail; together they were 93% of
    the device's log volume. Event-driven DEBUG logs (calibration, command
    responses, error paths) are unchanged.
    check-device.py:
    - climate now asserts the derived "air_quality" text sensor. The ENS160
    eco2/tvoc/aqi sensors are `internal: true` in the package, so they are
    never published over the native API and could never pass.
    - motion_speed range widened to [-10, 10]; the C4002 reports signed
    velocity (negative = ap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
    [dfrobot_c4002.cpp]
2026-08-04 Fix PZEM pin assignments: TX=GPIO15, RX=GPIO33
    Physical wiring was confirmed GPIO15→PZEM RX and GPIO33←PZEM TX.
    Updated CLAUDE.md GPIO table and hardware summary, and power-pzem004t.yaml
    comment examples to reflect the verified prototype pin assignment.
    GPIO39 freed up (was incorrectly listed as PZEM RX).
    PZEM module itself is defective (echoes Modbus requests but generates
    no responses) — replacement needed before power monitoring will work.
2026-08-05 Switch C4002 component to upstream git source (cdjq/esphome dev)
    Swap external_components from local path to the upstream git repo so we
    track the vendor's component directly. The sensitivity_threshold number
    entity (our local addition) is not present in upstream; removed from
    motion.yaml. Deployed and verified: motion PASS on room-sensor-poe2.
2026-08-05 C4002: replace calibration failure message with threshold readback
    analysis_text_report() now publishes the raw per-gate thresholds from
    both door types (M:[...] E:[...]) instead of a misleading failure
    string. The thresholds are always set by the device; this makes the
    actual values visible in HA after calibration.
    [dfrobot_c4002.cpp]
2026-08-05 C4002: complete redesign — ceiling presence, room geometry, per-gate calibration
    Replaces the Arduino-port-style component with a purpose-built ceiling presence
    sensor. Key changes:
    - Room geometry (width/depth/ceiling_height) as substitutions → detect_range
    computed at codegen time via slant-range trig (Python math.sqrt)
    - Single binary_sensor presence output (replaces template + target_status sensor)
    - OUT_MODE2 (presence-only, was Mode_3 motion+presence)
    - Calibration: start_env_calibration(5, 30) + read per-gate thresholds on
    countdown=0, apply max(sensitivity_floor, gate[i]) per gate, write back
    - sensitivity_threshold is a per-gate floor, not a blanket override
    - presence bina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
    [dfrobot_c4002.cpp]
2026-08-06 C4002: add Radar Gates text sensor showing per-gate bitmask and target energy
    Extends C4002Listener with on_detection_detail() carrying the full detection
    payload. New C4002GateStatusSensor publishes on every 1s tick:
    E: ......#......#. | 480cm e34 (EXIST: 15-gate bitmask, closest dist+energy)
    M: ......M........ | 480cm e34 +25cm/s (MOVE: single gate marker + velocity)
    -- (NO_BODY)
    MOVE is handled even though OUT_MODE2 only outputs static presence — if the
    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
2026-08-06 check-device: update motion check for new C4002 entities
    Replaces old entity checks (target_status, motion_distance, etc.) with
    the redesigned interface: presence binary sensor, radar_gates text sensor,
    radar_log text sensor, and radar_calibrate switch.
2026-08-06 text_sensor: replace #/. gate bitmask with Braille energy levels
    Active gates (dominant) scale ⣀→⣿ by energy; other threshold-crossed
    gates fixed at ⣦; inactive gates at ⣀ baseline.
2026-08-10 deploy: drop the colocated container stack, point at ws://esphome:6052/ws
    The agent no longer runs in a dedicated `claude` sidecar provisioned by
    deploy/docker-compose.yml — it runs beside the builder in an environment that
    already shares the repo bind mount. The compose stack, its Dockerfile and its
    .env.example described a setup that no longer exists, so remove them.
    The builder is reachable in-network as `esphome`, not `esphome-builder`
    (verified: server 1.0.12, esphome 2026.6.2, requires_auth=false). Correct the
    endpoint in CLAUDE.md, the deploy-device skill and builder-deploy.py.
    Since the client now only ever talks to the unauthenticated in-network builder,
    strip the out-of-network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
2026-08-10 climate: smooth temperature/humidity, drop poll rate to 60s
    Add a 5-sample sliding-window moving average to both the temperature and
    humidity sensors and raise update_interval from 10s to 60s. Each published
    value is now an average over the last 5 minutes, emitted once a minute — the
    aht10 readings were noisier than the resolution warranted for room climate.
2026-08-10 claude: track worktree bgIsolation setting
    Shared (not .local) so the setting applies for anyone working in this repo.
2026-08-20 Updated PCB to Rev 2 and 3
    [RoomSensor-BackPlate.kicad_pcb, RoomSensor-BackPlate.kicad_sch, RoomSensor-MainPlate.kicad_pcb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]
2026-08-20 utility-sensor: bring the metering node back under repo control
    The utility sensor was configured directly in the ESPHome dashboard and lost
    its config when the builder was rebuilt. Restore it as packaged YAML, with the
    three configuration changes it was missing.
    Packages:
    base/utility-sensor — esp-idf + Ethernet/OTA/API, no I2C (GPIO03/04 are the
    pump Modbus TX and a meter input here)
    sensors/water-flow — one metered line; include once per line with `vars`
    sensors/well-level — QDY30A over Modbus
    sensors/energy-sdm — Eastron SDM, ready but not enabled (RS485 unpopulated)
    Configuration added:
    • Well level is now published as the column abo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
    [utility-sensor.yaml]
2026-08-20 utility-sensor: real well geometry, build-time pulse calibration
    Well: probe at 1500 cm, pump intake at 1600 cm — the probe hangs ABOVE the
    intake, so the offset is +100 cm. The formula `raw + (pump - sensor)` already
    handles either geometry; only the sign changes. Fixed the package's comment,
    which claimed probe-below-intake was the normal case, and redrew the diagram.
    That geometry does cost measurement range: a submersible transmitter reads 0
    once uncovered and cannot see a surface below itself, so every level in the last
    100 cm above the intake — the range that decides whether the pump runs dry —
    publishes as 100 cm. Added binary_sensor.well_probe_uncovered (device_class:
    problem)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
    [utility-sensor.yaml]
2026-08-20 water-flow: per-line volume reset button; updated meter calibrations
    The `restore: true` total is keyed off the sensor's object_id, so it survives an
    OTA — re-flashing after a calibration change leaves the volume that was
    accumulated under the old pulses/L in place, with no way to clear it short of
    erasing flash. Add a "Water Volume Reset - <line>" template button per line
    firing sensor.integration.reset.
    Also picks up the measured per-line calibrations (897 / 1077 / 595) and teaches
    check-device.py to assert the buttons are present.
    [utility-sensor.yaml]
2026-08-20 builder-deploy: actually upload — install only compiles
    Deploying utility-sensor surfaced this: the builder's firmware/install job ends
    at "Successfully compiled program" and never contacts the device. The OTA is a
    separate firmware/upload job (job_type: upload), which the script never called —
    so every deploy through this script has reported green while leaving the device
    on its old firmware.
    deploy_one now runs firmware/install (compile) then firmware/upload (OTA), each
    streamed via firmware/follow_job, and fails if either job fails. Verified: the
    script now exits 1 on a failed upload instead of reporting success.
    Also documents that neither this environment nor (currently) the build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
2026-08-20 Edit utility-sensor.yaml
2026-08-20 utility-sensor: correct device IP to 10.10.14.10; deployed
    The device answers at 10.10.14.10, not the .11 the pre-repo config carried. The
    OTA failure "[Errno 113] No route to host" on port 3232 was ARP finding nothing
    at .11 — it reads like a container routing fault, so document that this error
    means "check device_ip" rather than "fix the network".
    Deployed and verified: OTA successful, check-device.py 27/27 pass. All eight
    flow/volume pairs and reset buttons present, well level reading 656 cm with
    well_probe_uncovered OFF.
2026-08-20 utility-sensor: aggregate "total" water line, defined on the device
    Stand-in for a real whole-house meter: two `combination: sum` sensors over the
    four DOMESTIC supply lines (EG/OG kalt + warm) — not the heating circuits, not
    the well. Volume sums the per-line totals rather than integrating the summed
    flow, so the total can never drift from the parts it is made of, and resetting
    any line moves it automatically (hence no reset button of its own).
    Defined in the device YAML rather than as a package: it is one device's
    aggregate of that same device's lines, and a package would have needed four
    `total_line_N` vars purely to hand back ids the device already knows.
    check-device.py grows a DEVI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
2026-08-20 packages: default GPIOs to MainPlate Rev 2/3; disable serial logger in base
    Rev 2/3 rewired the main plate substantially. Pin assignments were read out of
    the new netlists (footprint->pad->net in both .kicad_pcb files, cross-referenced
    against the symbol pin names) rather than from the old docs:
    I2C SDA GPIO4 -> GPIO13 radar TX GPIO2 -> GPIO4
    I2C SCL GPIO3 -> GPIO33 radar RX GPIO36 -> GPIO35
    PZEM TX GPIO33 -> GPIO3 PCF8574 INT -> GPIO36 (new)
    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
